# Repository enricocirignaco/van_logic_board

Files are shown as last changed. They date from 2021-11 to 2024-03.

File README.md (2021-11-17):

# van_logic_board

link to bracker switch 100A : https://www.amazon.de/LONXAN-Trennschalter-Netzschalter-Anti-Leckage-Knopf-Familienauto%EF%BC%8CAusr%C3%BCstung/dp/B096MD13M2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

Fuel Gauge IC used in thi project: BQ34Z100-G1: https://www.ti.com/lit/ds/symlink/bq34z100-g1.pdf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

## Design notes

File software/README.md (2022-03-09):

Node Red running on a docker container. Image used is the official node-red image.

#### Setup Dev Enviroment:

- navigate to project location
- create project: `docker run -it -p 1880:1880 -v ${PWD}:/data --name node-red nodered/node-red`
- to stop container run `docker stop node-red`
- to start container and attach to it run `docker start -a node-red`
  Source: https://nodered.org/docs/getting-started/docker

## GPIO configuration:

### Outputs

- Fridge
  - enable: GPIO23 (HW 16)
  - disable: GPIO22 (HW 15)
- Charger
  - enable: GPIO8 (HW 24)
  - disable: GPIO25 (HW 22)
- Inverter
  - enable: GPIO18 (HW 12)
  - disable: GPIO17 (HW 11)

- Source Select **(ON = lead battery, OFF = lfp battery)**: GPIO24 (HW 18)
- Pump: GPIO13 (HW33)
- Aux output: GPIO12 (HW32)

### Inputs

- Switch kitchen (low active): GPIO6 (HW 31)
- Switch living room (low active): GPIO16 (HW 36)
- Aux input 1: GPIO20 (HW 38)
- Aux input 2: GPIO21 (HW 40)

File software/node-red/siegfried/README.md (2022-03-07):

# Node RED Project documentation

The project is divided in multiple flows:

- Hardware Layer
-
-
-

## Hardware Layer

In this flow state of output gpios is set and state of input gpios is read.

### Outputs

This part of the flow is triggered from external flows. An Switch Flow redirect the msg payload accordingly to the msg topic.
To change the state of an Hardware Output the message must have the following syntax:

- msg.payload = state of output
- msg.topic = output name

#### Name of outputs and its possible states:

- fridge (boolean)
  - true
  - false
- charger (boolean)
  - true
  - false
- inverter (boolean)
  - true
  - false
- battery_select (string)
  - lfp_battery
  - lead_battery
- pump(boolean)
  - true
  - false
- aux_output (boolean)
  - true
  - false

### Bistable Relais

The hardware is equipped with bistable relais in order to save energy. Each relais has a "turn on coil" and a "turn off coil".
The software was so implemented that 100ms after one of both coils is turned on then both coils are turned back off.

## Inputs

As the state of any gpio input changes this part of the flow is triggered and and the state of each input stored in a global object is updated. The state of the inputs is also updated when the flow is deployed.

### Name of inputs stored as global variables:

- input_state (object)
  - switch_kitchen
  - switch_living_room
  - aux_input_1
  - aux_input_2

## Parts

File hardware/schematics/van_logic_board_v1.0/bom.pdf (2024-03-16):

Name | Description | Designator | Manufacturer Part Number 1
Raspberry Pi Zero | Raspberry Pi Zero with Header | BRD1
100nF 25V | Capacitor | C4
10uF 25V | Capacitor | C5
1N4148WS | DIODE GEN PURP 75V 150MA SOD323F | D1, D13, D14, D15, D16, D17, D24, D25, D26, D27 | 1N4148WS
MMSZ4678T1G | Zener Voltage Regulator, 500 mW, 2-Pin SOD-123, Pb-Free, Tape and Reel | D2, D3 | MMSZ4678T1G
BAT54C | Schottky Barrier Diode, 30 V, 3-Pin SOT23, RoHS, Tape and Reel | D4, D5, D10, D18, D21
MMSZ5226BT1G | Zener Voltage Regulator, 500 mW, 2-Pin SOD-123, Pb-Free, Tape and Reel | D6, D7, D8, D9, D11, D12, D19, D20, D22, D23 | MMSZ5226BT1G
282836-2 | Female Header, Pitch 5 mm, 1 x 2 Position, Height 10 mm, Tail Length 3.5 mm, Rohs, Bulk | J1, J2, J3, J8, J9, J10, J11, J12, J13, J14, J15, J16, J17, J18, J19, J20, J21 | 282836-2
JST-S3B-PH-SM4-TB-3_V | JST-S3B-PH-SM4-TB-3_V | J4, J5, J7
JST-S4B-PH-SM4-TB-3_V | JST-S4B-PH-SM4-TB-3_V | J6
Jumper | THT Vertical Pin Header WR-PHD, Pitch 2.54 mm, Single Row, 2 pins | P1 | 61300211121
AO3400A | MOSFET N-CH 30V 5.7A SOT23 | Q1, Q2, Q3, Q7, Q8, Q10, Q12, Q13, Q24, Q25, Q26, Q27
LTV-827S-TA1 | OPTOISOLATOR 5KV 2CH TRANS 8-SMD | Q4, Q5, Q6, Q15, Q17 | LTV-827S-TA1
FDD86250 | MOSFET N-CH 150V 8A DPAK | Q9, Q11, Q14, Q16, Q18, Q19, Q20, Q21, Q22, Q23 | FDD86250
700kΩ | Resistor | R1, R6
10kΩ | Resistor | R2
100kΩ | Resistor | R3, R7, R8, R9, R11, R12, R17, R18, R21, R22, R23, R24, R27, R28, R32, R33, R34, R36, R39, R40, R43, R44, R47, R48, R51, R52
4.1kΩ | Resistor | R4, R5, R10
4.7kΩ | Resistor | R13, R14, R15, R16, R19, R20, R25, R26, R29, R30
1kΩ | Resistor | R31, R35, R37, R38, R41, R42, R45, R46, R49, R50
12v to 5v power supply | 12V TO 5V buck converter | U1
| 16-Bit, Multi-Channel Delta-Sigma Analog-to-Digital Converter with I2C Interface and On-Board Reference, 8-Pin SOIC 150mil, Extended Temperature | U2 | MCP3426A0-E/SN
PCA9685PW,112 | 16-Channel, 12-Bit PWM Fm+ I2C-Bus LED Controller, 2.3 to 5.5 V, -40 to 85 degC, 28-Pin TSSOP (SOT361-1), RoHS, Tape and Reel | U9 | PCA9685PW,112

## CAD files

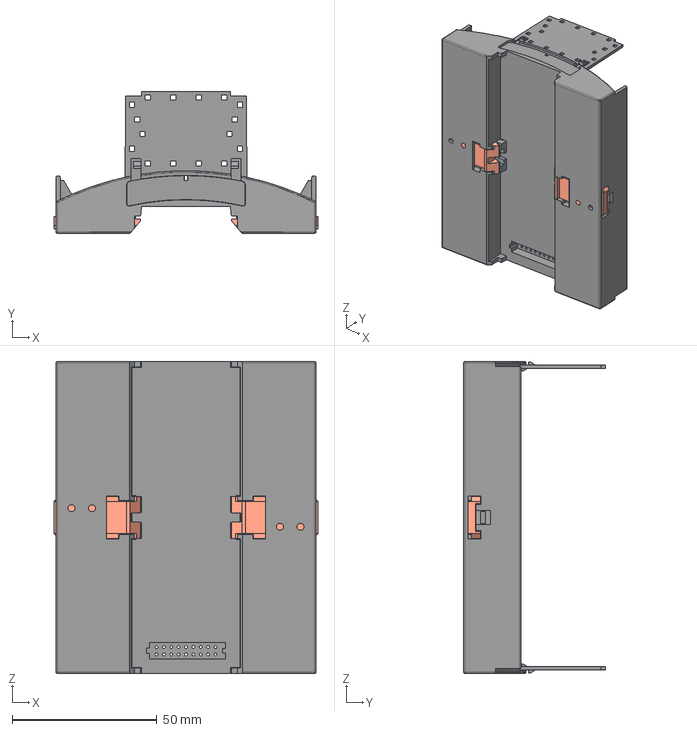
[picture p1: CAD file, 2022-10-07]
resources/step_models/pxc_2896270_06_BC-107-6-UT-HBUS-BK_3D.stp
91.0 x 48.9 x 107.6 mm
BC_107.6_GEH-UT_HBUS__H.Select__00383663
Fussriegel_14.4_L30_Sperr_H.Select__00370451_Nr2 x 2

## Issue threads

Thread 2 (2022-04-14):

broker bugfix

enricocirignaco, 2022-04-14:
charger try to use lead battery and fridge want to use fridge battery

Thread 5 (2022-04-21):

battery gage won't change color

enricocirignaco, 2022-04-21:
question posted on stack overflow

enricocirignaco, 2022-06-05:
issue found and fixed.
changes must be applied to van software. The following code must be applied too the parser node of the battery gauge
```
// calculate power
msg.payload = Math.round((msg.payload.I/1000) * (msg.payload.V/1000));

// if charger is on and battery is not full (not absorption nor float state)
if(global.get("output_state.charger") && msg.payload.CS !=4 && msg.payload.CS !=5){
    const charger_power = Math.round(4*msg.payload.V/1000);
    msg.payload = msg.payload + charger_power;
}

// ui stuff --> change gage color if is charging or discharging
if(msg.payload > 0 && context.get("color") != "green" ){
    context.set("color", "green");
}
else if(msg.payload <= 0 && context.get("color") != "red") {
    context.set("color", "red");
}
else {
    // remove sign
    msg.payload = Math.abs(msg.payload);
    return msg;
}

// remove sign
msg.payload = Math.abs(msg.payload);
msg.ui_control =
{
    "gtype": "gage",
    "colors": [context.get("color"), context.get("color"), context.get("color")],
};

return msg;
```

Closed 2022-07-22.

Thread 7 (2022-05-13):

Inrush current limiter for inductive load (fridge)

enricocirignaco, 2022-05-13:
A circuit to limit the inrush current of the fridge's inductive load must be implemented --> suggestion ICL NTC (inrush current limiter negative temperature coefficient resistor)

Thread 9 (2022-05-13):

Power Supply redesign

enricocirignaco, 2022-05-13:
The current power supply must be replaced with a DC-DC converter

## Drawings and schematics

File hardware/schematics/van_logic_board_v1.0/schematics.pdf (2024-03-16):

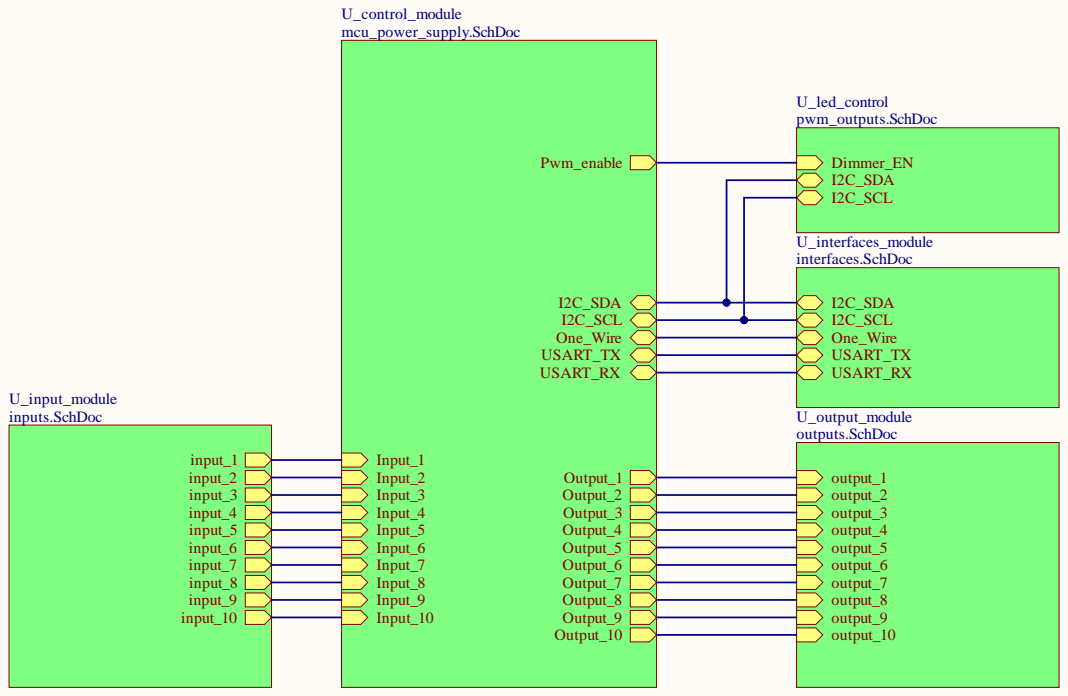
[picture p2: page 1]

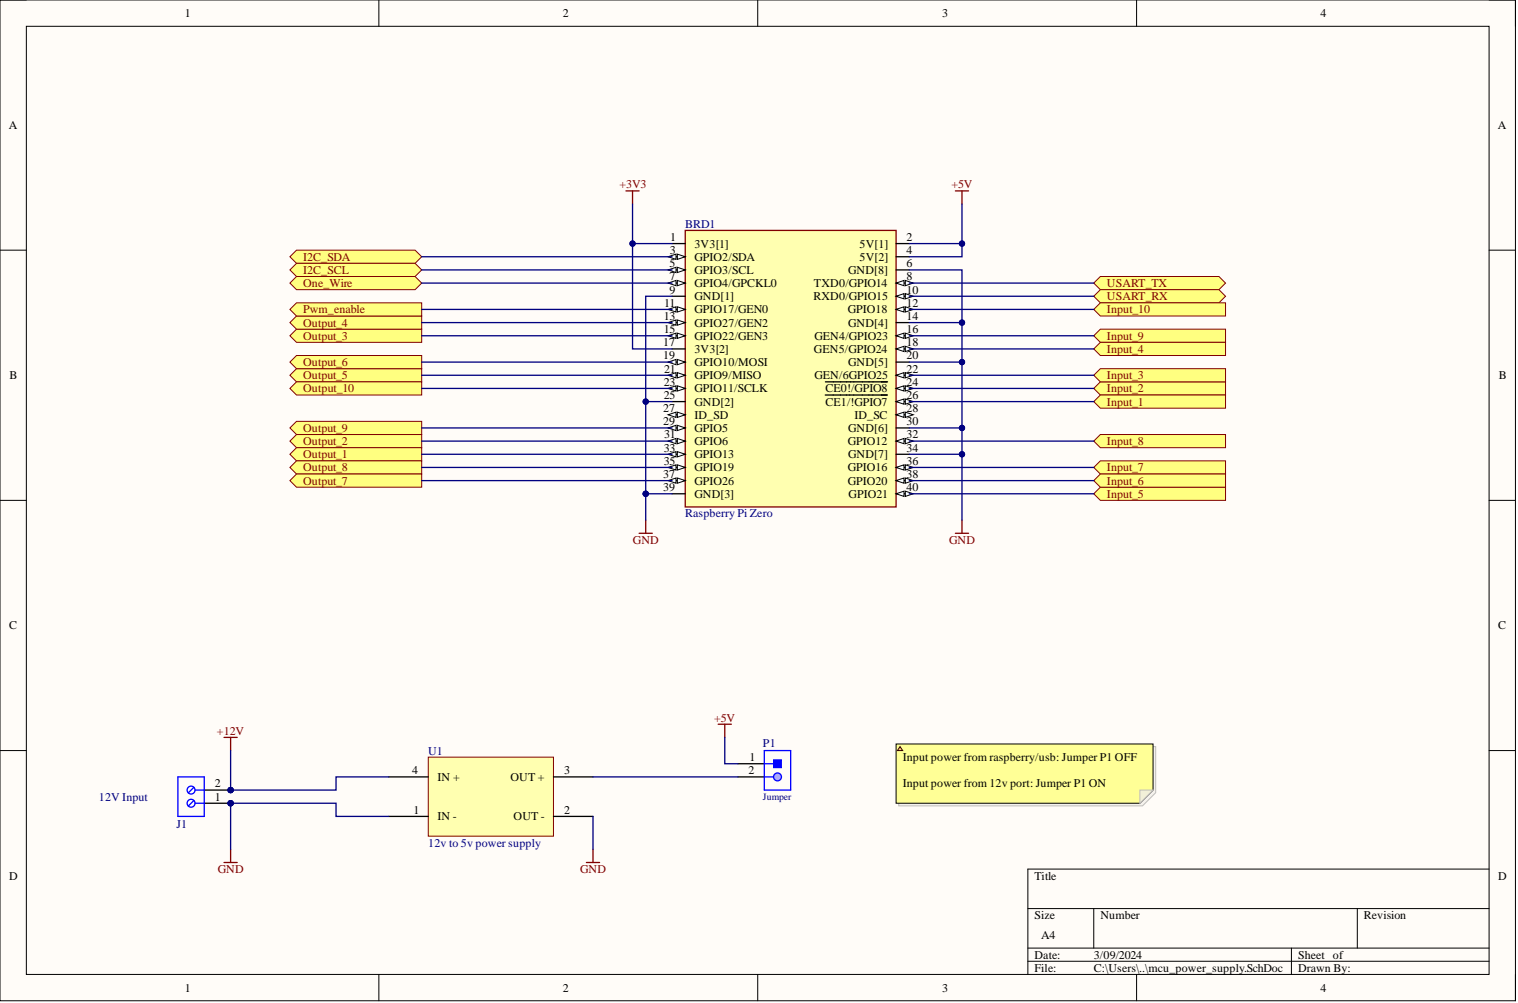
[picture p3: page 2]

Input power from raspberry/usb: Jumper P1 OFF

Input power from 12v port: Jumper P1 ON

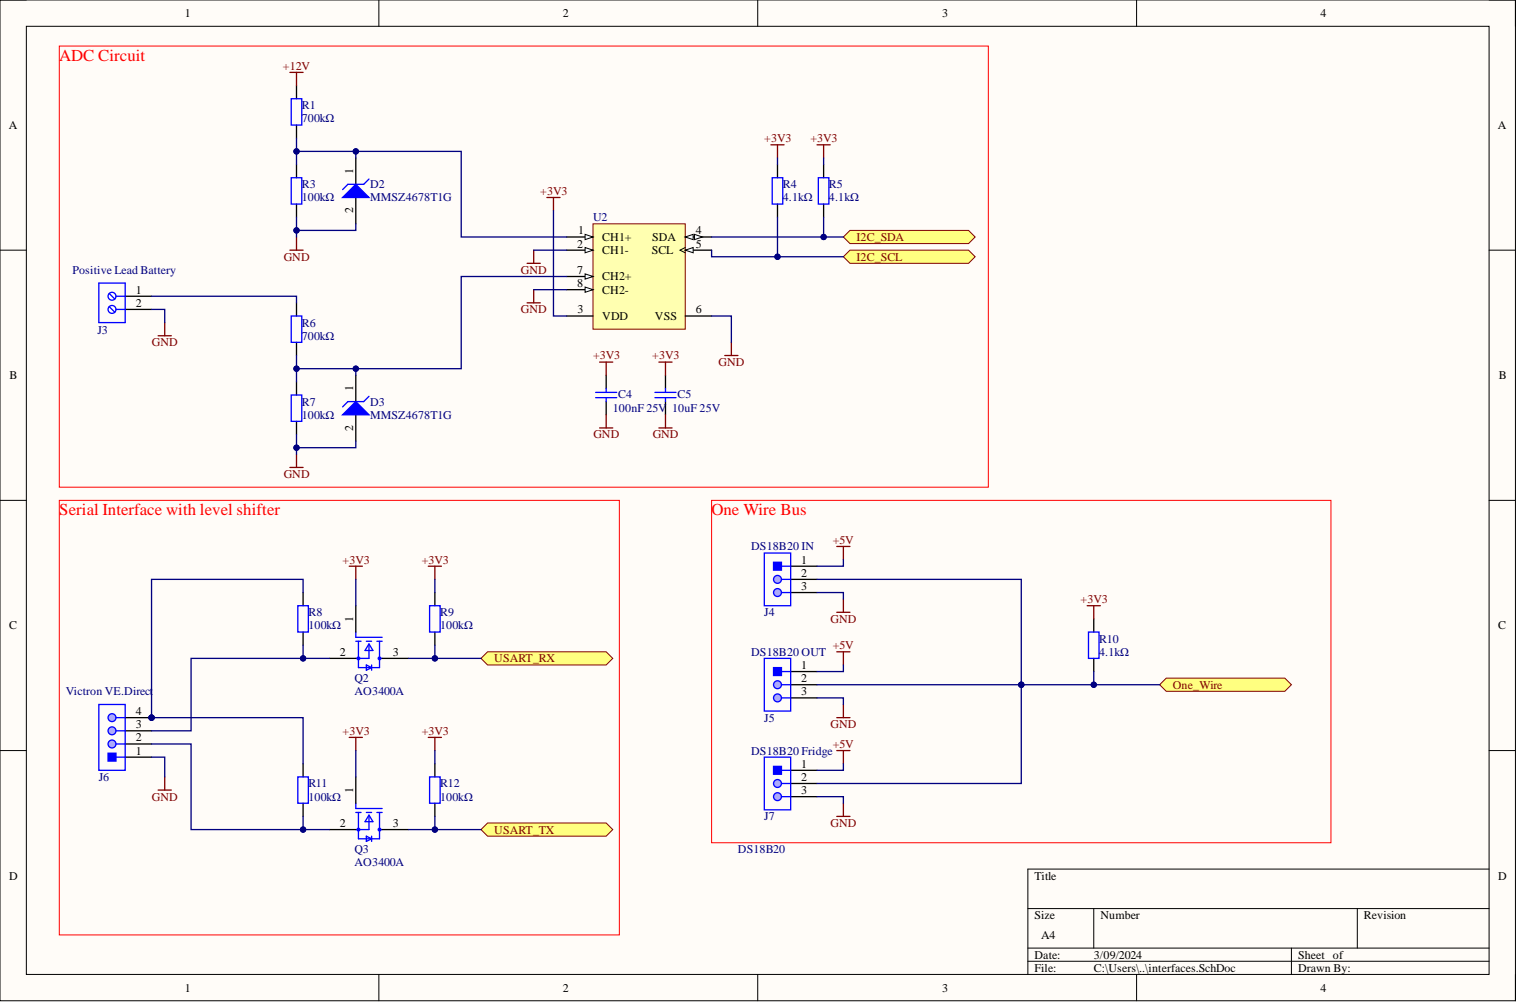
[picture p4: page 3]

Serial Interface with level shifter

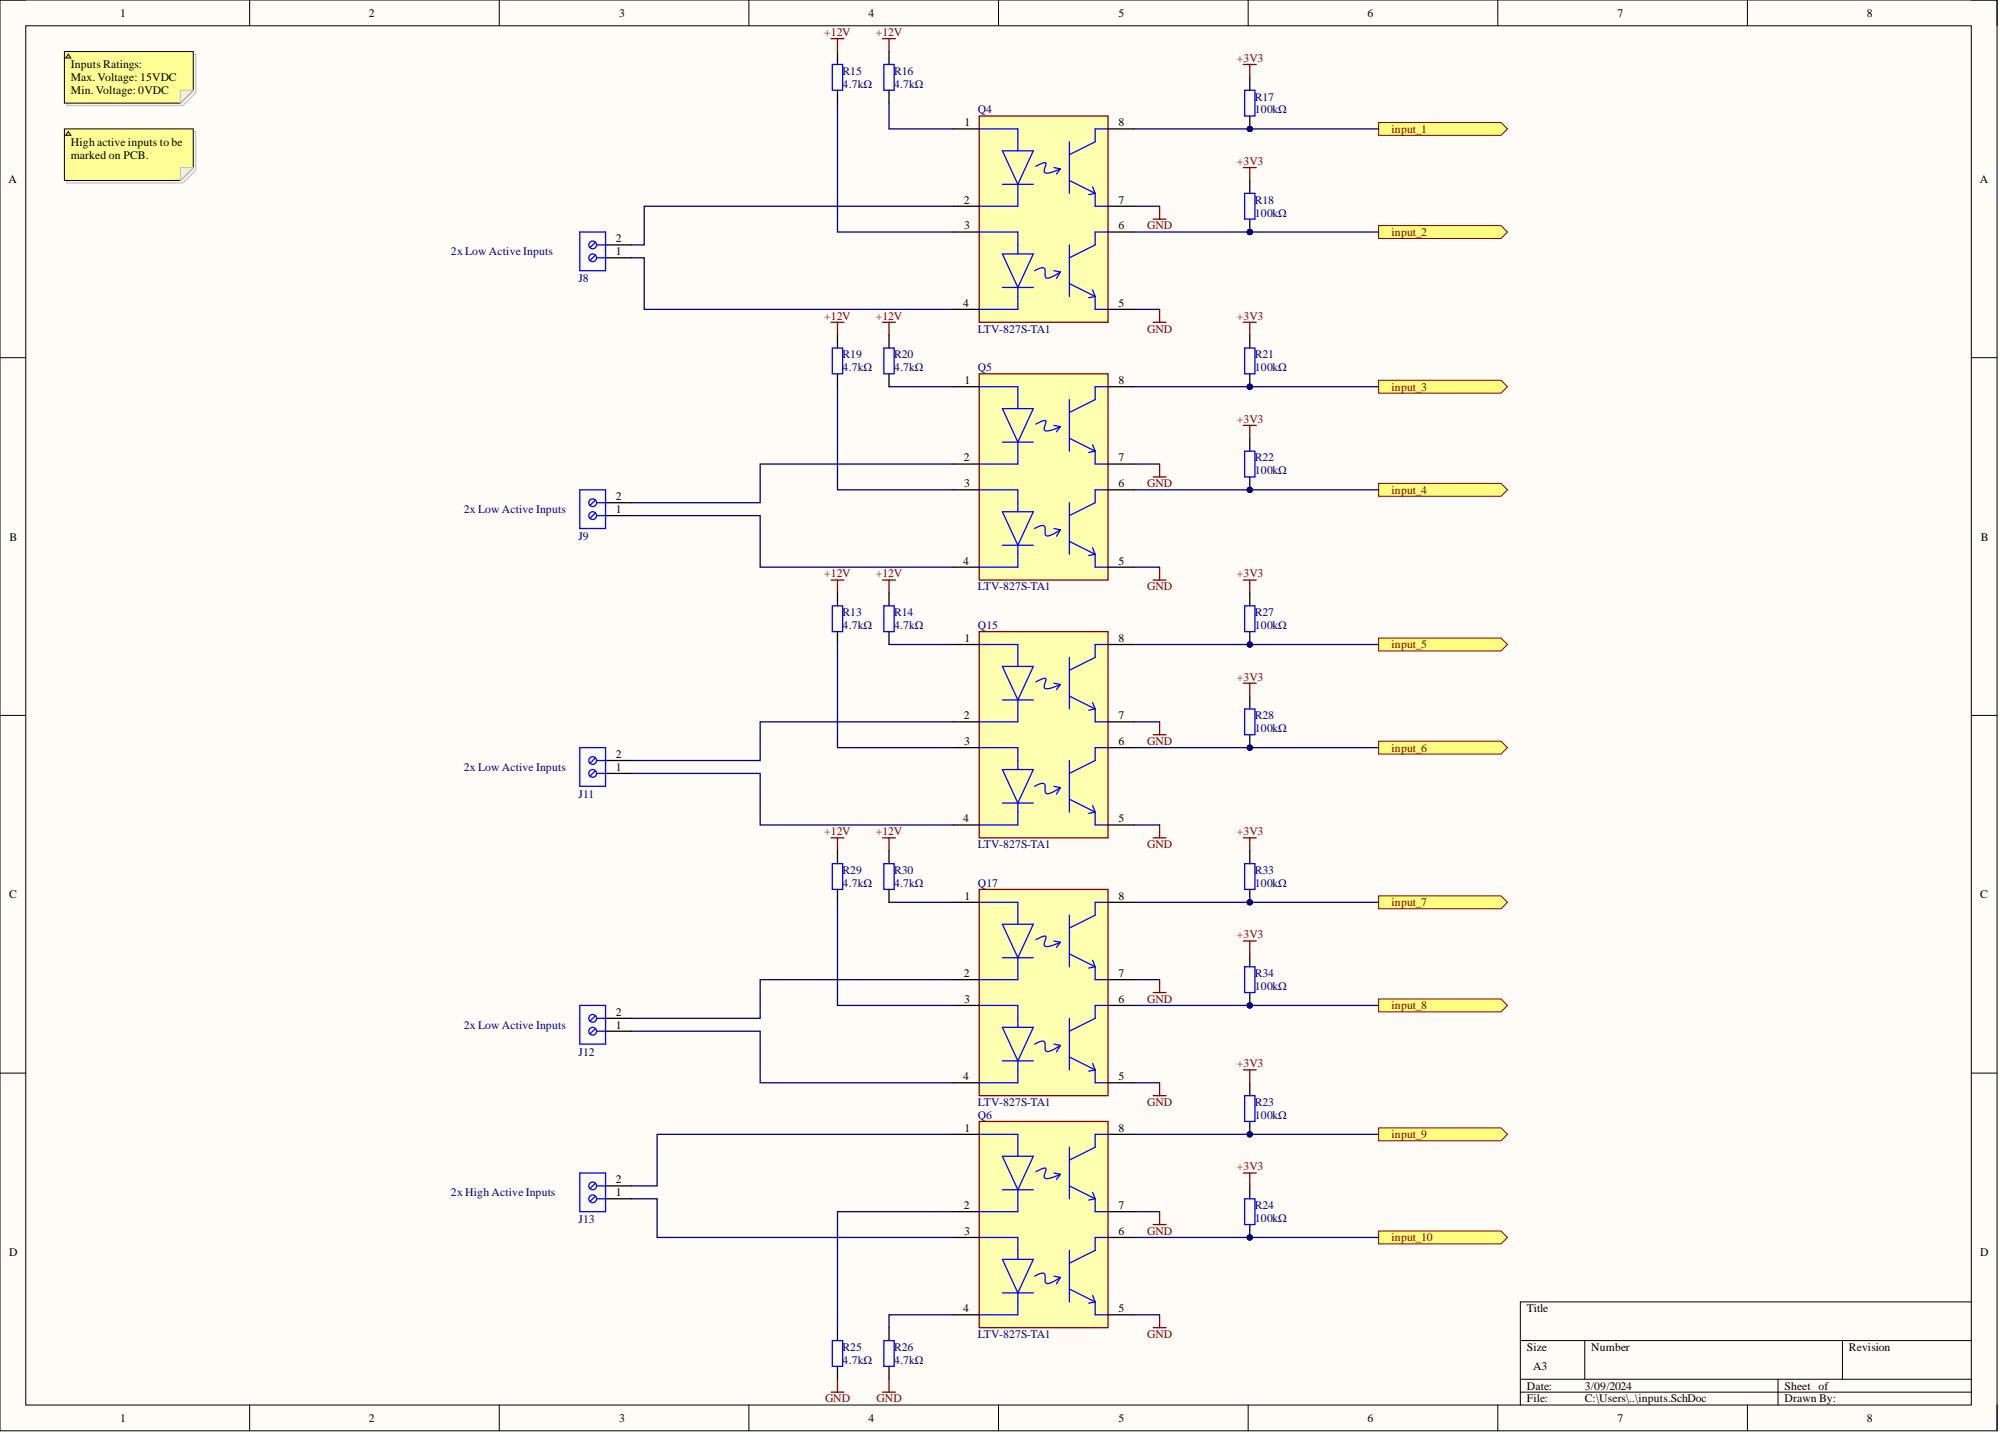
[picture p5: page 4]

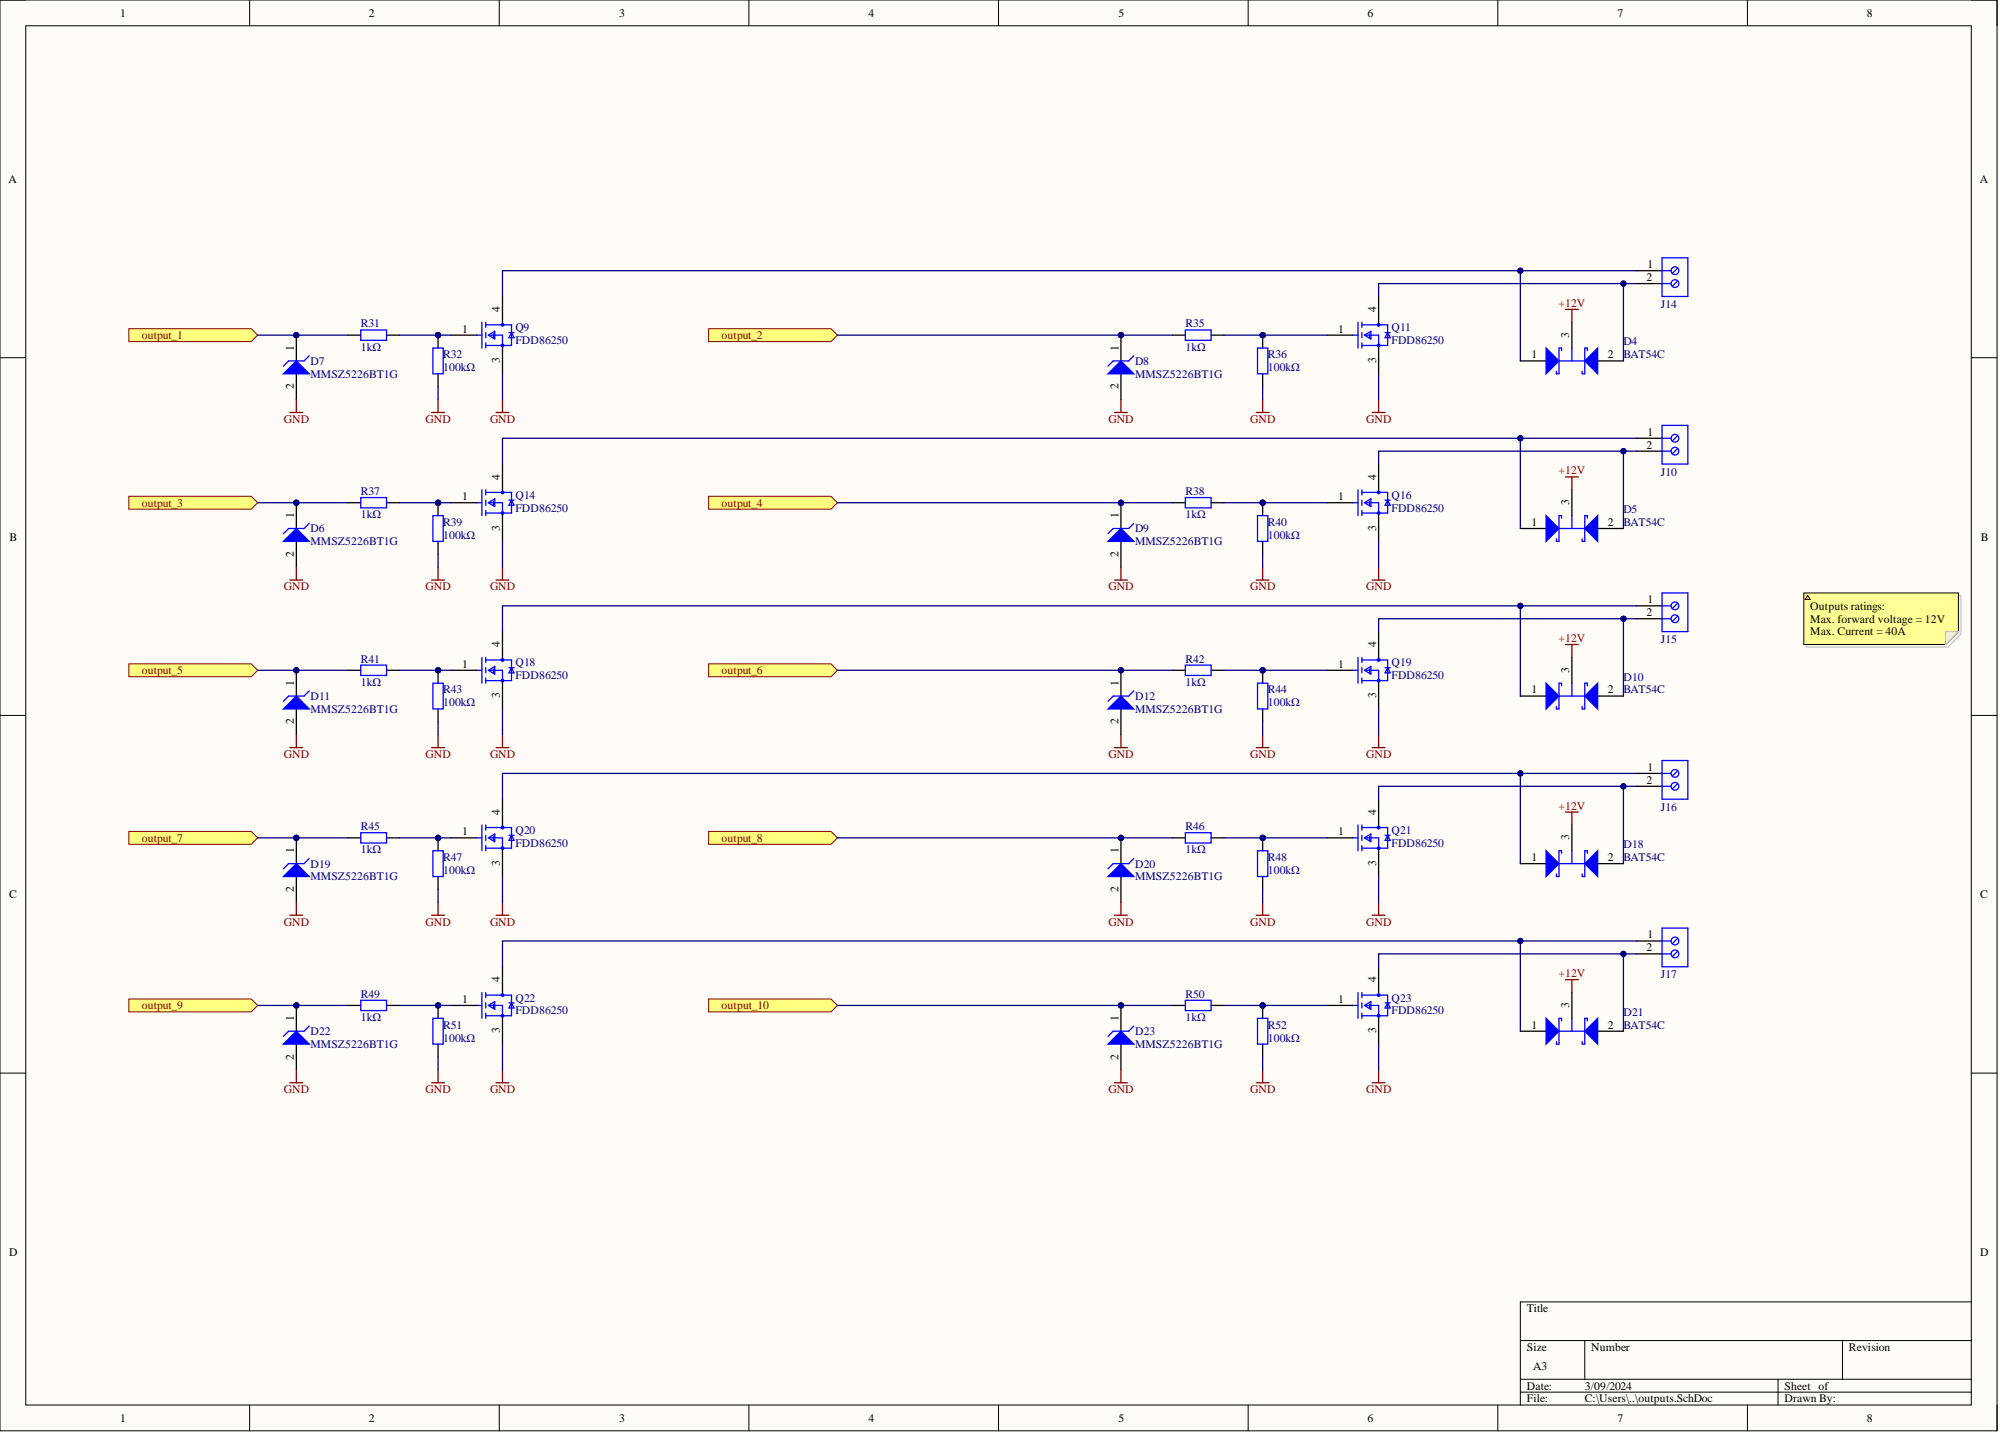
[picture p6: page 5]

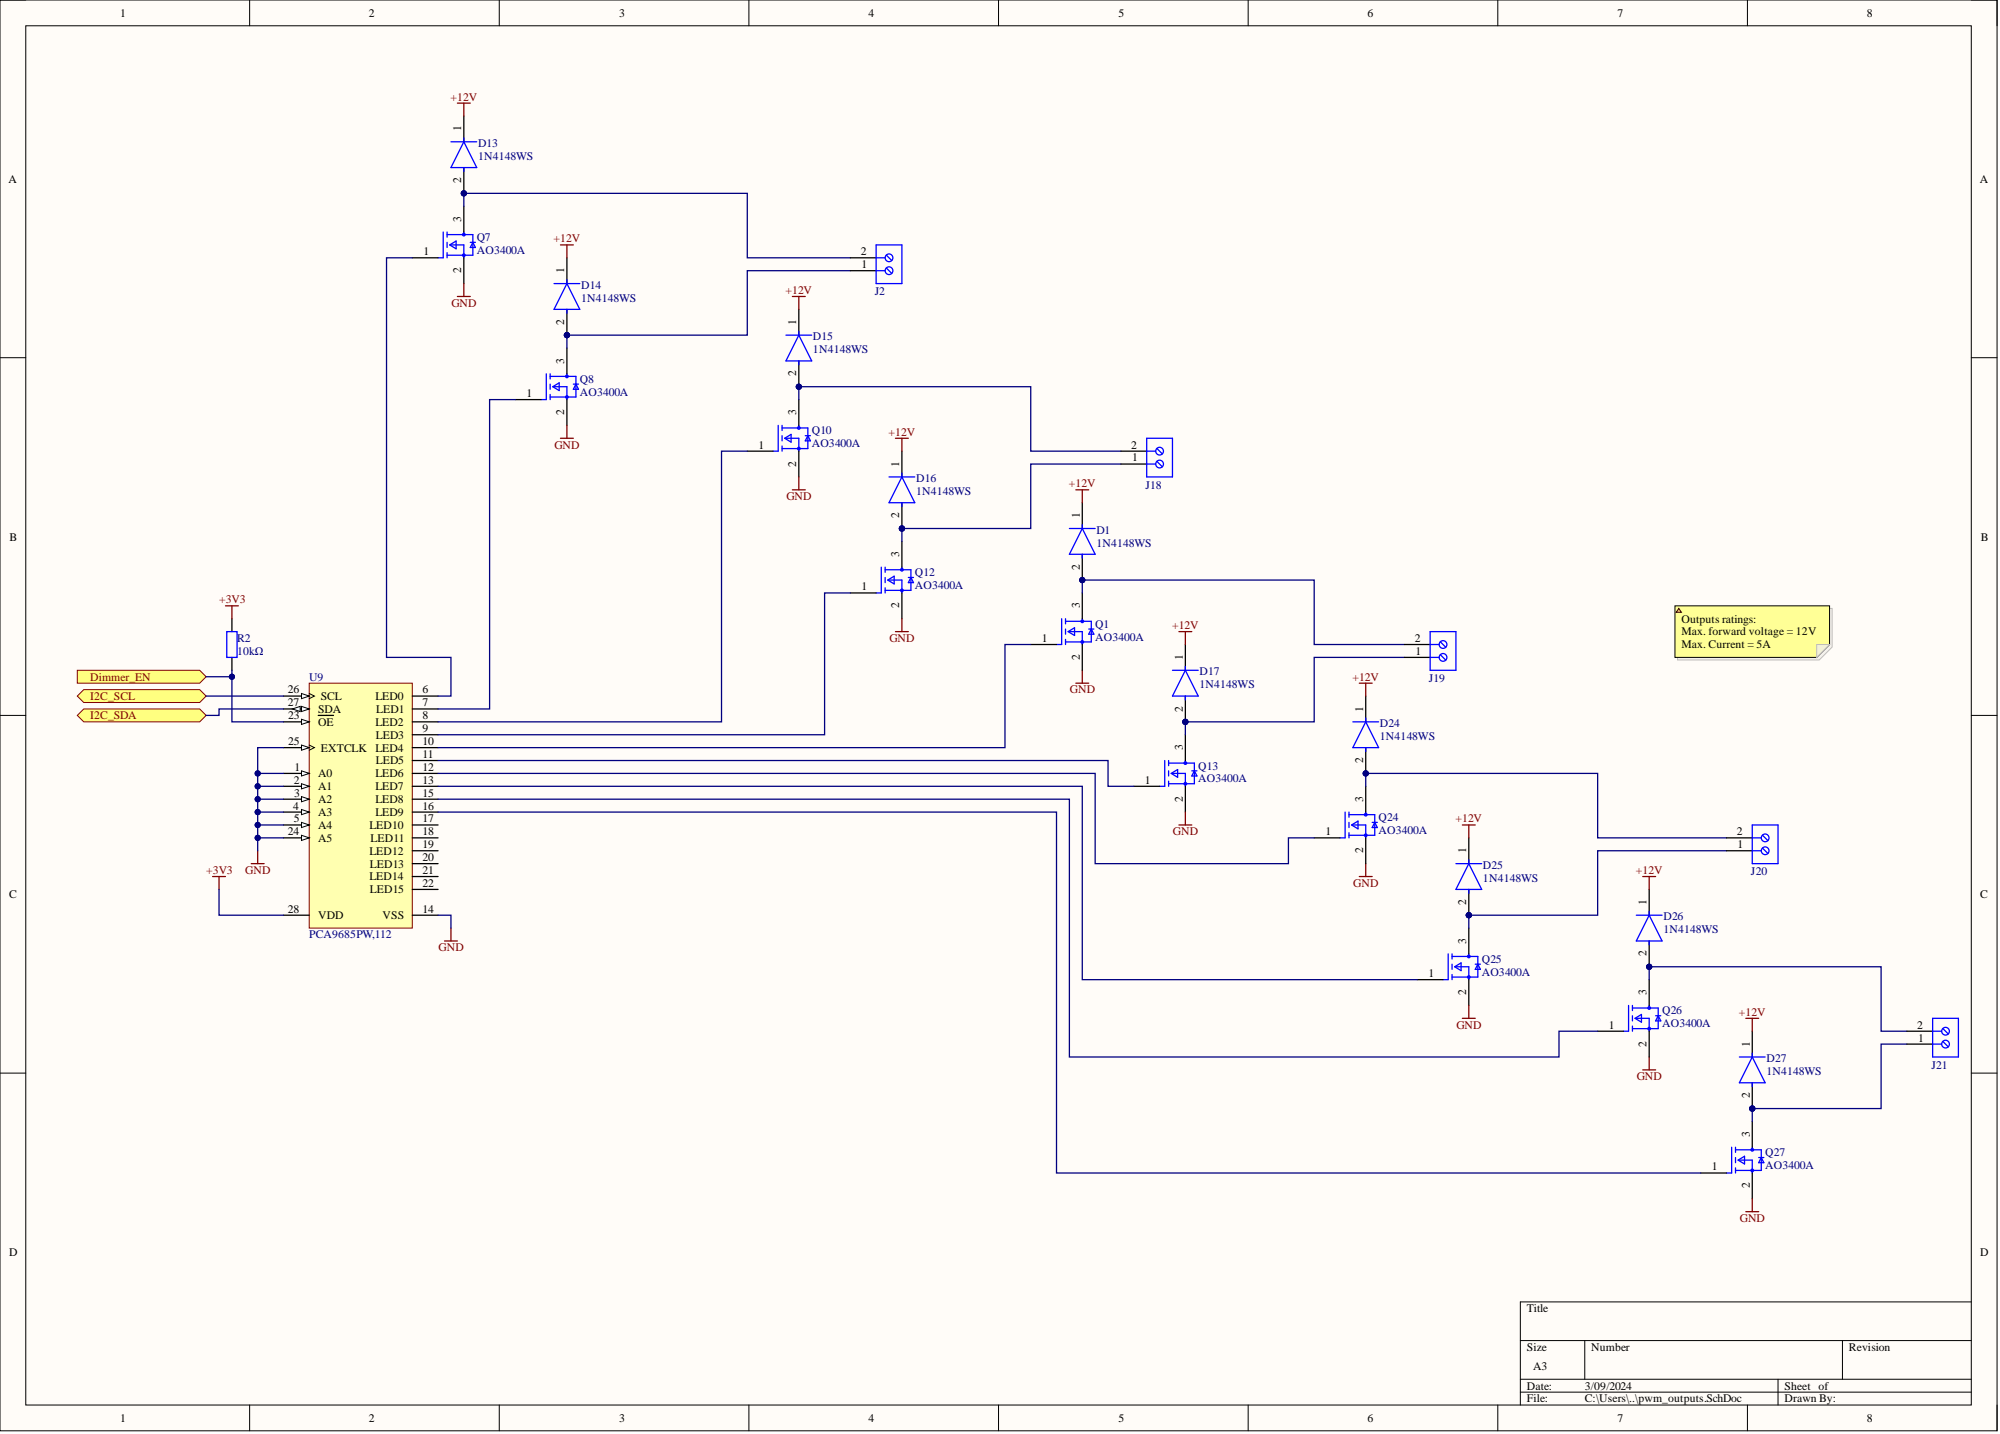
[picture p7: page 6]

2 | | 1 3
3 | | 1 5
4 | | 1 6
5 | | 1 7 | D | 1 | Q 2 4 A O 3 4 0 0 | +1 2 V
2 4 | | 1 8

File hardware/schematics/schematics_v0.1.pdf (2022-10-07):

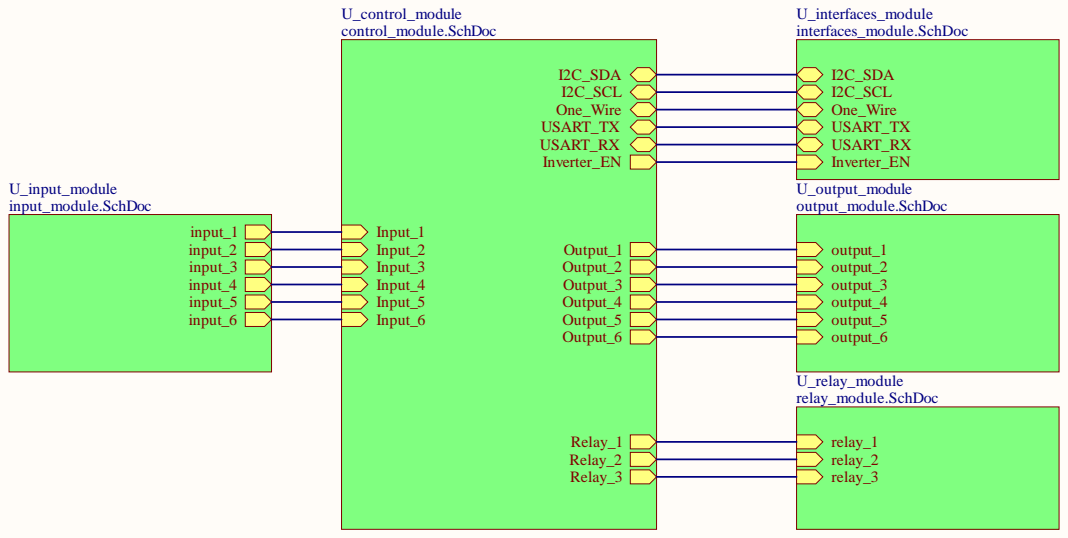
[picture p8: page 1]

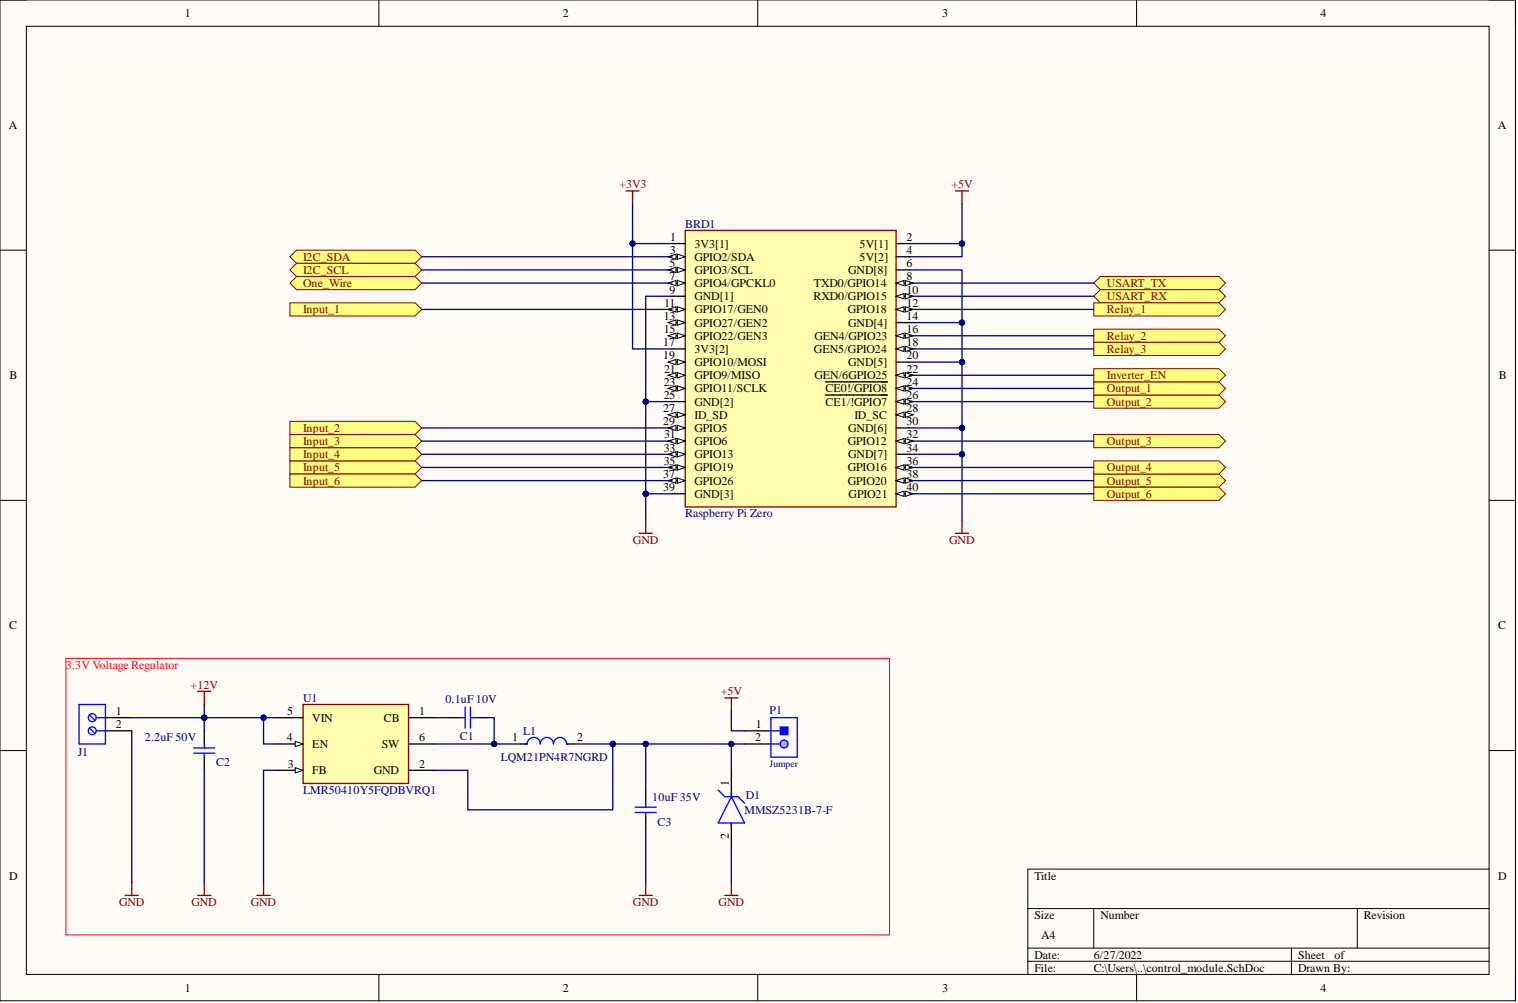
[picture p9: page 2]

1 0

1 9 2 2 2 | | 2 0
1 | 2 2
3 | 2 4
5 | 2 6
2 7 2 3 3 3 3 3 | | 2 8 0

3 2
3 4
3 6
3 8
4 0

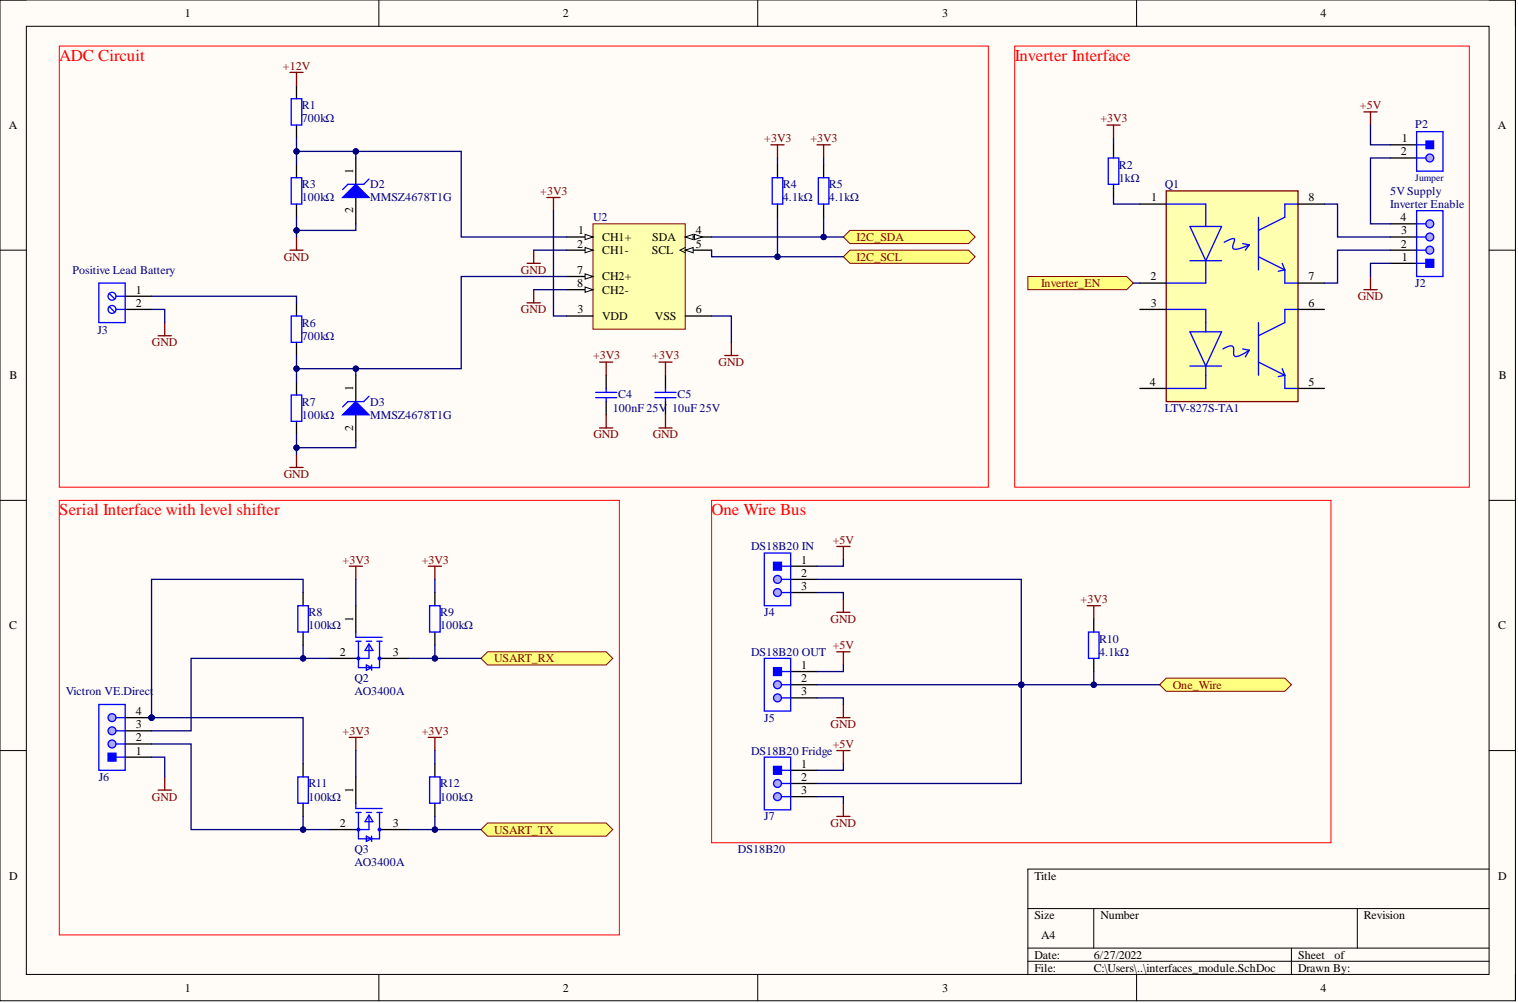
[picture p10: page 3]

Serial Interface with level shifter

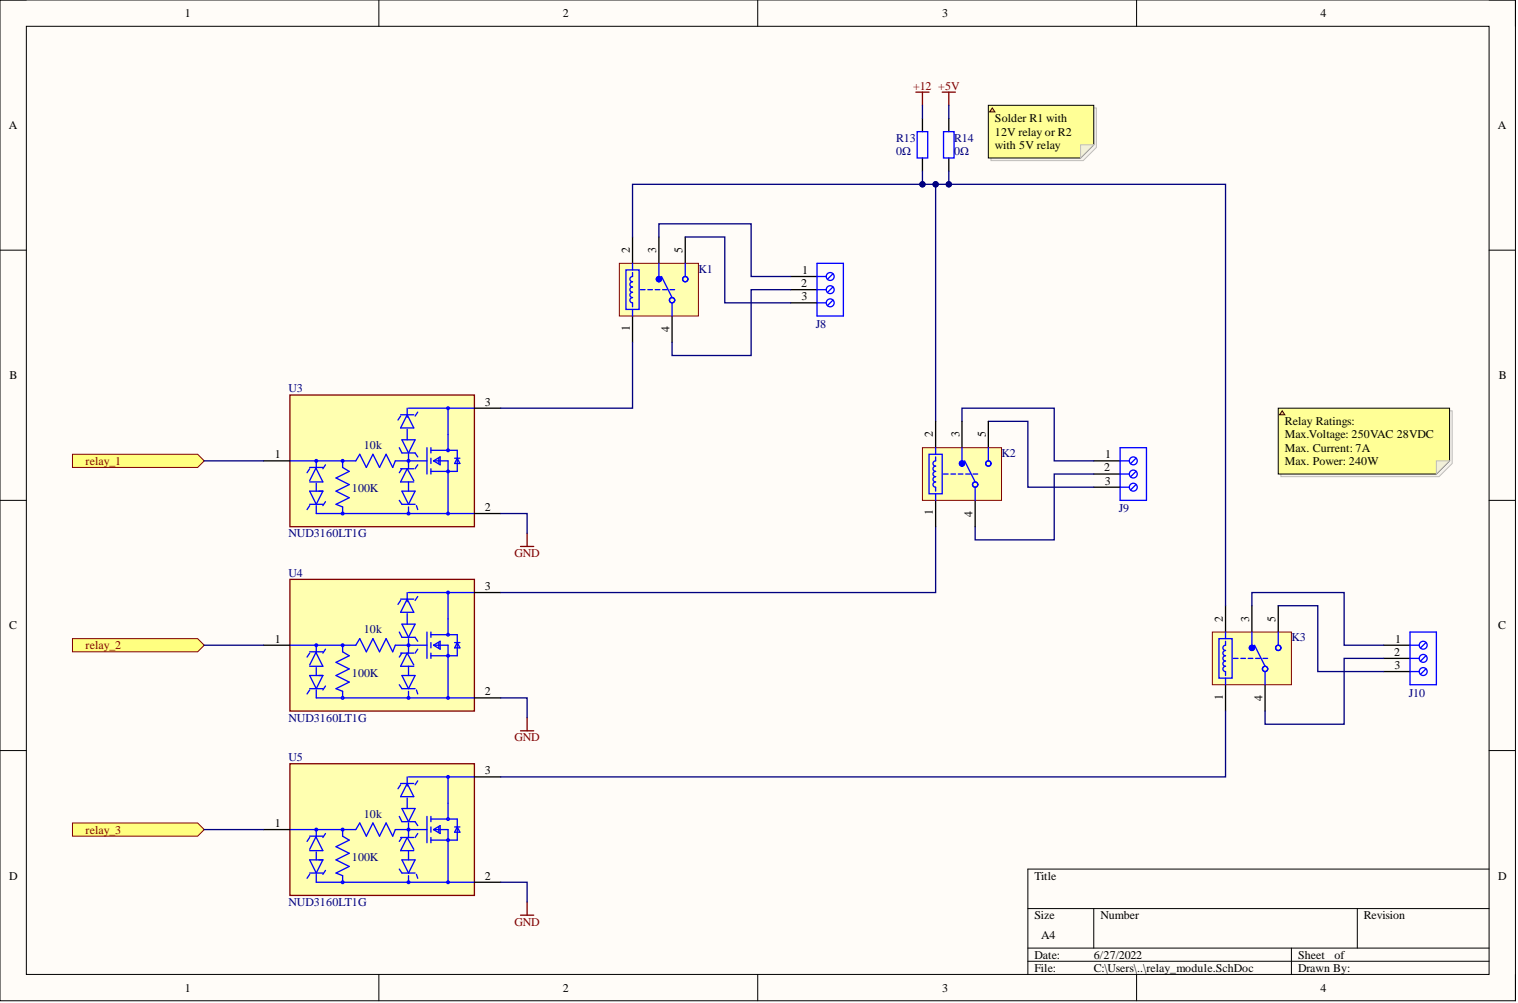
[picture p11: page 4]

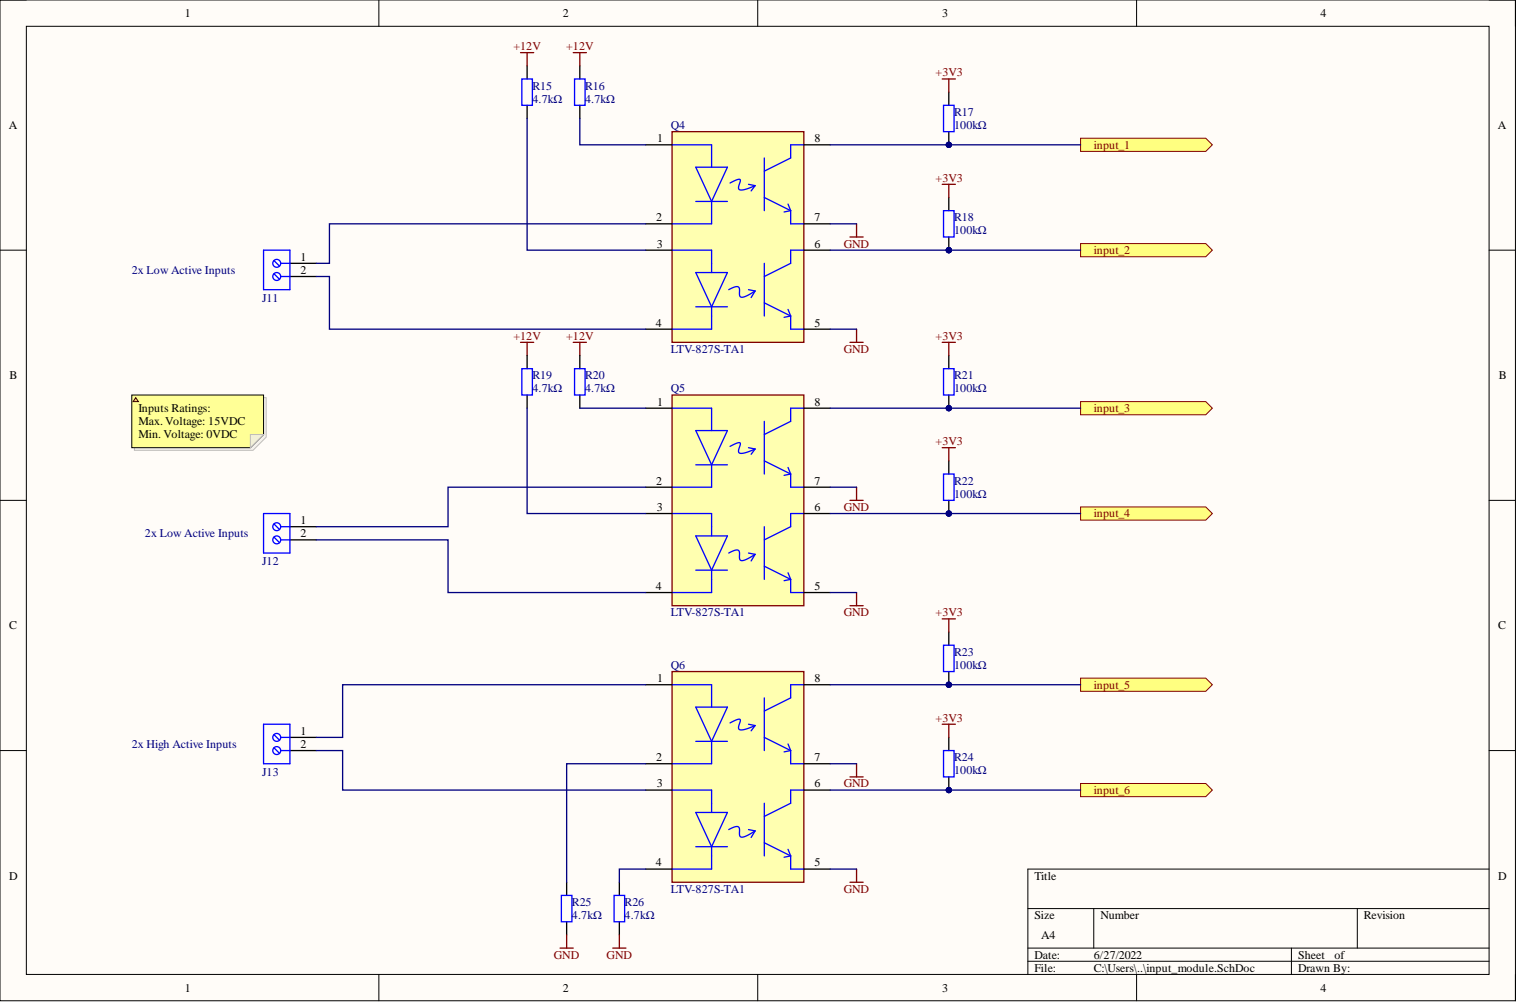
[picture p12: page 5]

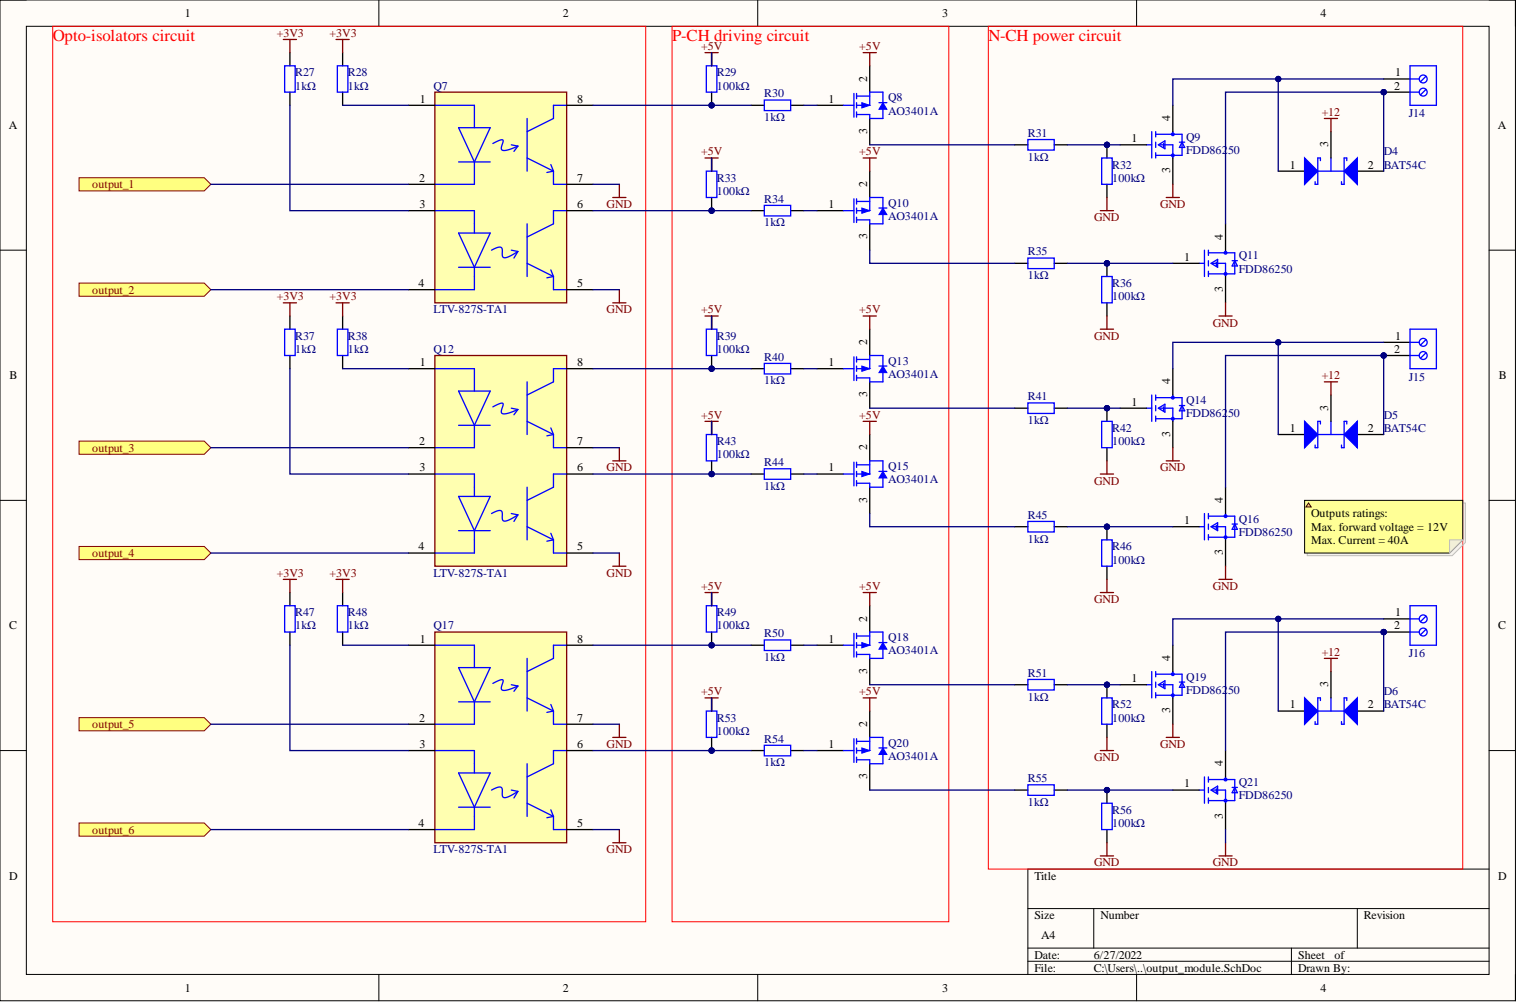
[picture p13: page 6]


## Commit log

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2021-11-15 inverter module fittet with power select and enable circuits
    [inverter_module.SchDoc]
2021-11-15 MCU circuit added to control module
    [control_module.SchDoc]
2021-11-15 bugfix:inverter module
    [inverter_module.SchDoc]
2021-11-15 fridge enable and temperature sensor circuits added to fridge module
    [fridge_module.SchDoc]
2021-11-15 schematics for water system module created
    [water_system_module.SchDoc]
2021-11-15 driver circuit for water pump and flow sensor circuit added to water system module
    [water_system_module.SchDoc]
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2021-11-17 i2c entries created in control module
    [control_module.SchDoc]
2021-11-17 SOC module added to main schematics
    [main.SchDoc]
2021-11-17 schematics library added to project
    [Schlib.SchLib, van_logic_board.PrjPcb]
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2021-11-25 inverter module modified. inverter enable relay changed with a double coil latching relay
    [inverter_module.SchDoc]
2021-11-25 SOC module deleted from project. trying to define state of charge with data from mptt
    [SOC_module.SchDoc]
2021-11-25 fridge module modified. double coil latching relay added
    [fridge_module.SchDoc]
2021-11-25 minor changes to water system module
    [water_system_module.SchDoc]
2021-11-25 sensors module schematics added to project
    [sensors_module.SchDoc]
2021-11-25 control module redesign with raspberry pi
    [control_module.SchDoc]
2021-11-25 second iteration almost done. Power supply needed
    [Schlib.SchLib, fridge_module.SchDoc, main.SchDoc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]
2021-12-26 same improovements to the schematics
    [PcbLib.PcbLib, Schlib.SchLib, control_module.SchDoc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]
2021-12-26 pump driver changed with more powerful one
    [water_system_module.SchDoc]
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2021-12-26 power suply for sensor changed from 3v3v to 5v
    [fridge_module.SchDoc]
2021-12-26 power supply changed for most ICs
    [interfaces_module.SchDoc]
2021-12-26 relay for inverter enable changed
    [inverter_module.SchDoc]
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2021-12-26 minor changes after review
    [charger_module.SchDoc, interfaces_module.SchDoc, van_logic_board.PrjPcb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]
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2021-12-28 all missing footprints added
    [PcbLib.PcbLib, Schlib.SchLib, charger_module.SchDoc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]
2021-12-29 footprint and symbol for terminal blocks added. Terminal blocks added to schematics and pcb
    [PcbLib.PcbLib, Schlib.SchLib, charger_module.SchDoc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]
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2022-01-30 draftsman document added to project
    [van_logic_board.PrjPcb]
2022-01-30 connector for temp sensor changed
    [fridge_module.SchDoc]
2022-01-30 pump driver circuit redesign (70W pump) input for tank level and output for solenoid added
    [water_system_module.SchDoc]
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2022-01-30 Mounting holes added to pcb
    [control_module.SchDoc, logic_board.PcbDoc, main.SchDoc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]
2022-01-31 Production files exported. V0.2 ready for production
    [inverter_module.SchDoc, logic_board.PcbDoc, van_logic_board.PrjPcb]
2022-01-31 pcb production files added to project
    [logic_board.GBL, logic_board.GBP, logic_board.GBS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]
2022-02-16 error fund, voltage regulator must be changed
    [control_module.SchDoc]
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2022-04-03 forgot to commit, a lot done. teperature over 1-wire and voltage over I2C implemented. bug fixed
2022-04-03 dashboard layout changed bugfix living room switch fixed
2022-04-07 bugfix charger when motor running
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2022-04-07 bugfix temp mesurments implemented without 1 wire node
2022-04-10 first prototype of the broker node
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2022-04-15 bugfix broker. dispute over power source. need testing issue #2
2022-04-21 bugfix battery capacity updated
2022-04-24 bugfix charger while running
2022-05-02 new altium project created for inverter board
    [inverter_board.PcbDoc, inverter_board.PrjPcb, inverter_board.SchDoc]
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2022-05-02 schematics & pcb first iteration done
    [inverter_board.PcbDoc, inverter_board.SchDoc]
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2022-05-12 fridge inverter and charger schematics condensed in a single relay module
    [charger_module.SchDoc, fridge_module.SchDoc, inverter_module.SchDoc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]
2022-05-12 input and output modules created
    [input_module.SchDoc, output_module.SchDoc]
2022-05-12 working on version 0.2
    [interfaces_module.SchDoc, main.SchDoc, van_logic_board.PrjPcb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]
2022-05-13 ntc added to relay circuit
    [relay_module.SchDoc]
2022-06-23 relay module modified with SPDT relay in SPST configuration
    [relay_module.SchDoc]
2022-06-24 relay module ready for routing
    [relay_module.SchDoc]
2022-06-24 input module ready for routing
    [input_module.SchDoc]
2022-06-24 output module ready for routing
    [output_module.SchDoc]
2022-06-24 some changes to pcb
    [control_module.SchDoc, interfaces_module.SchDoc, van_logic_board.PrjPcb]
2022-06-26 level shifter added to serial interface
    [interfaces_module.SchDoc]
2022-06-27 relay type changed for K2
    [relay_module.SchDoc]
2022-06-27 one imput changed from high active to low active
    [input_module.SchDoc]
2022-06-27 text frames added to output module
    [output_module.SchDoc]
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2022-06-27 flyback diodes added to outputs
    [output_module.SchDoc]
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2022-06-27 Voltage reg changed form 3v3 version to 5v version
    [control_module.SchDoc]
2022-06-27 zenner for ADC circuit changed from 3v to 1.8v version
    [interfaces_module.SchDoc]
2022-06-27 jumper for 5v selection added
    [control_module.SchDoc]
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2022-06-27 step files of the case added to repo
    [pxc_2896270_06_BC-107-6-UT-HBUS-BK_3D.stp]
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2022-06-29 bugfix: 12 line changed into 12v line
    [relay_module.SchDoc]
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2022-06-30 ting & minor bugfix
    [output_module.SchDoc, relay_module.SchDoc]
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2022-07-22 fix #5 battery gauge now changes color
2022-07-22 working on issue #12 new summer algorithm wrote with low battery and timeout function
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2022-08-20 Output now ramps from ~98% down to ~1% Dutycycle using a non inverting Intergrator to Charge the external Capacitor
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2022-10-06 schematics for high voltage controls added to PCB project
    [high_voltage_control.SchDoc, main.SchDoc]
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2022-10-08 highvoltage module connected to control module. connections name modified
    [control_module.SchDoc, high_voltage_control.SchDoc, main.SchDoc]
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2024-03-06 high voltage and relay modules deleted. 4x inputs added to input module
    [control_module.SchDoc, high_voltage_control.SchDoc, input_module.SchDoc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]
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2024-03-06 missing footprint created
    [PcbLib.PcbLib, Schlib.SchLib, mcu_power_supply.SchDoc]
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2024-03-09 bom and assemly files created. old projects deleted
    [PCB_Project_MCU.SchDoc, analog.SchDoc, inverter_board.PcbDoc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]
